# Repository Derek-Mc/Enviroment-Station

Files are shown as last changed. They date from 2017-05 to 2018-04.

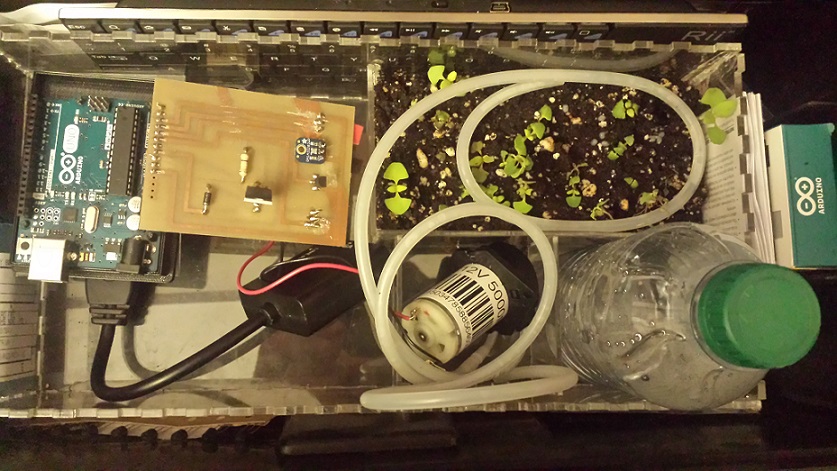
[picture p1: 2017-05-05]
Project Website/box2.jpg

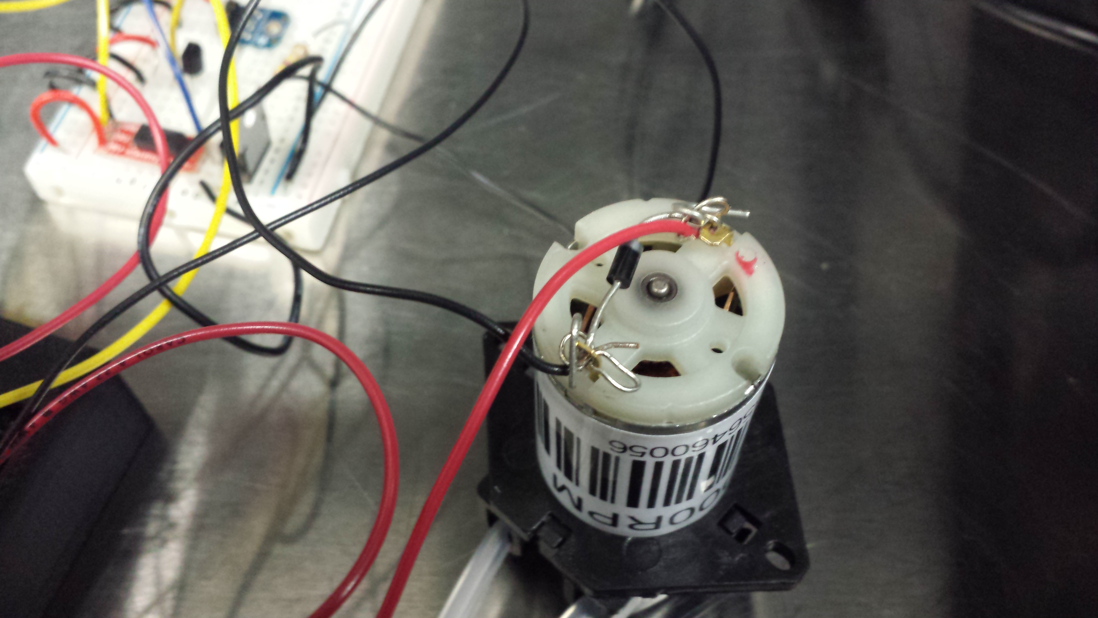
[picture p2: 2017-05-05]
Project Website/pump.jpg

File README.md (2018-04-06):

# Enviroment-Station
Keystone project from college (2017).

The objective of the project was to create an enviromantal monitoring station that would measure the humidity, light levels,
temperature, and soil moisture content of a plant.  This data is then sent to a server where the data is the pulled from and
displayed on an Android app and a website.

All files were made by myself with the exception of; Plant1.php, Plant_One_Hum.php, Plant_One_Light.php, Plant_One_Moist.php,
and Plant_One_Temp.php, which were created by my partner on the project.

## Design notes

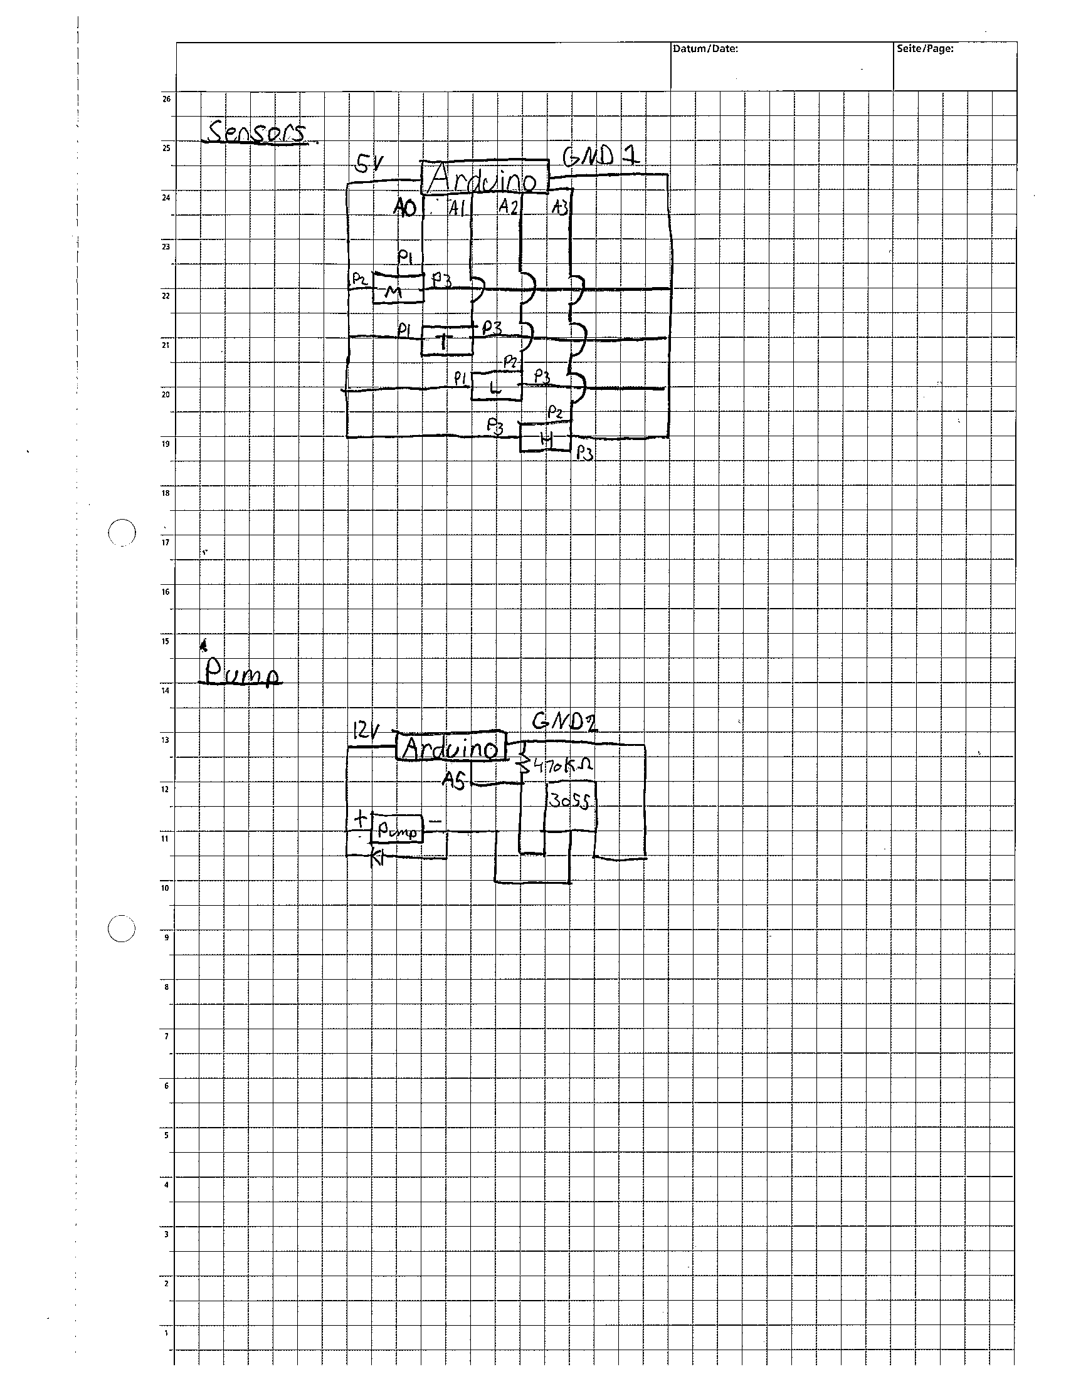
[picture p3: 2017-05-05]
Project Website/schematic.png

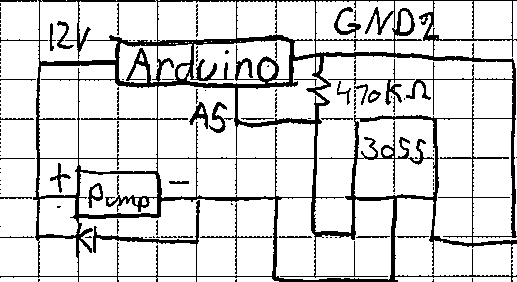
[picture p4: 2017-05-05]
Schematics/schematic2.png

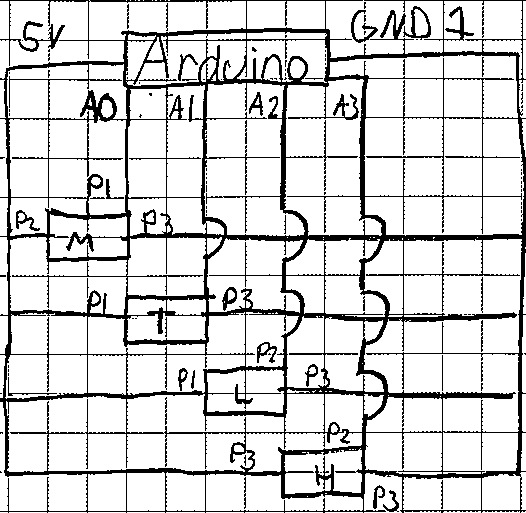
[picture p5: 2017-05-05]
Schematics/schematic1.png

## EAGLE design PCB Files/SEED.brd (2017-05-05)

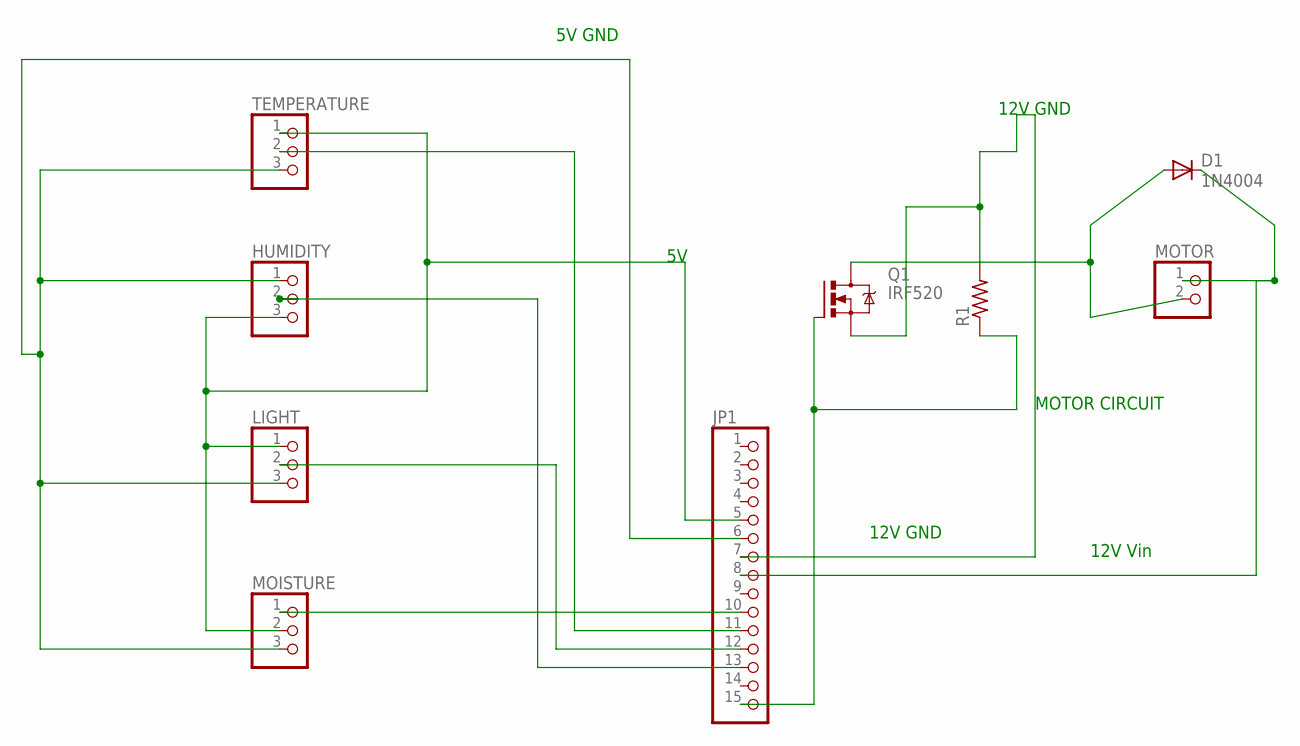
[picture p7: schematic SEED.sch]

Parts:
D1: 1N4004; DO41-10
HUMIDITY: PINHD-1X3; 1X03
JP1: PINHD-1X15; 1X15
LIGHT: PINHD-1X3; 1X03
MOISTURE: PINHD-1X3; 1X03
MOTOR: PINHD-1X2; 1X02
Q1: IRF520; TO220BV
R1: R-US_0207/12; 0207/12
TEMPERATURE: PINHD-1X3; 1X03

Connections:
unnamed: JP1.10, MOISTURE.1
unnamed: JP1.11, TEMPERATURE.2
unnamed: JP1.12, LIGHT.2
unnamed: HUMIDITY.2, JP1.13
unnamed: JP1.15, Q1.G, R1.1
unnamed: D1.A, MOTOR.2, Q1.D
unnamed: HUMIDITY.3, JP1.5, LIGHT.1, MOISTURE.2, TEMPERATURE.1
unnamed: D1.C, JP1.8, MOTOR.1
unnamed: JP1.7, Q1.S, R1.2
unnamed: HUMIDITY.1, JP1.6, LIGHT.3, MOISTURE.3, TEMPERATURE.3

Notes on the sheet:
MOTOR CIRCUIT
12V Vin
12V GND
5V GND

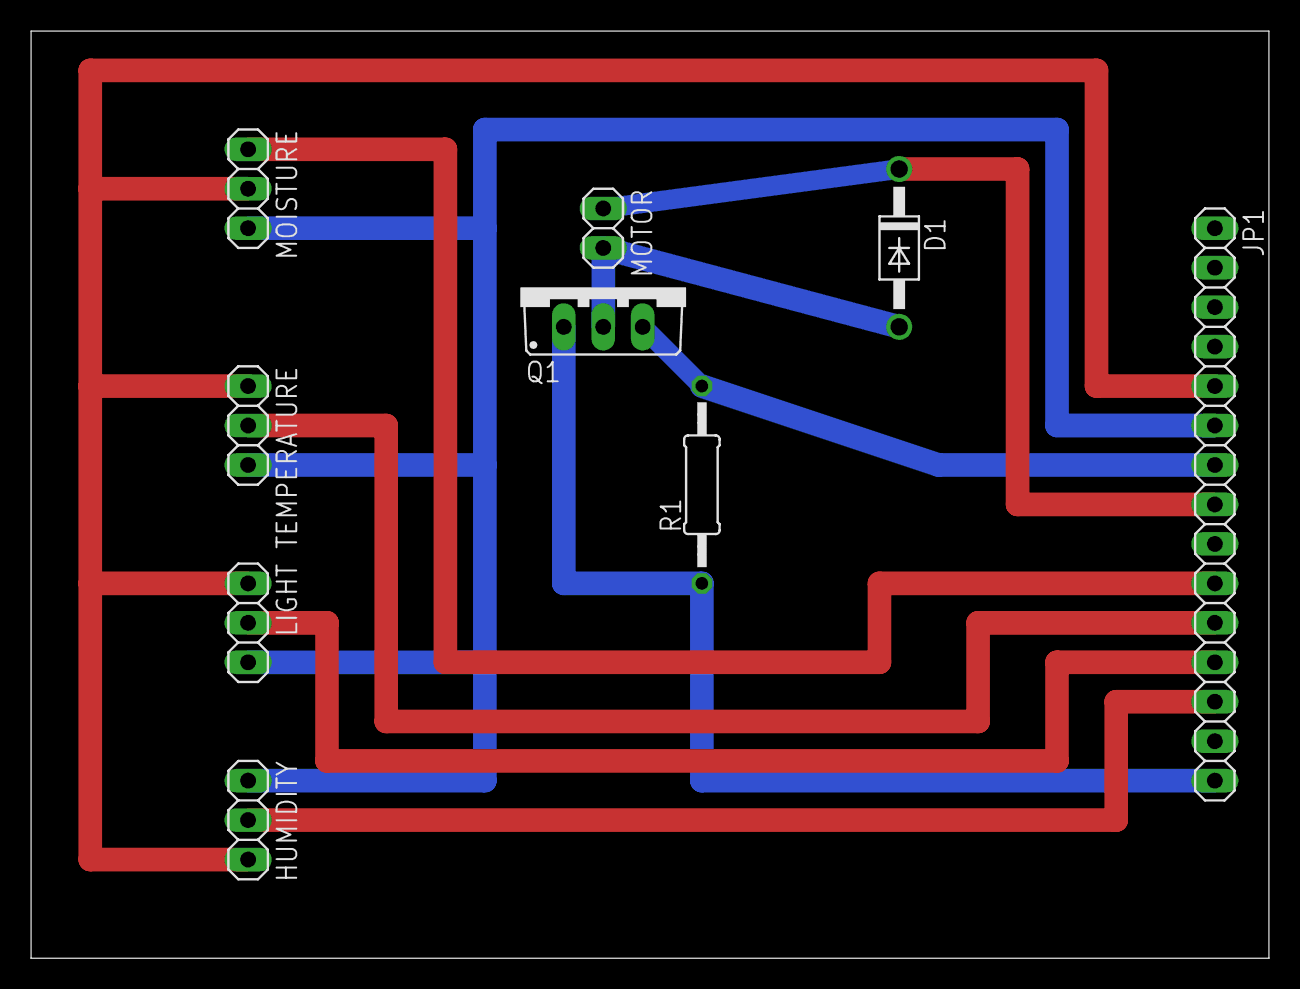
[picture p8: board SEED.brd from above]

Board: 2 copper layers, 79.7 x 59.7 mm, 9 parts (0 on the bottom side), 10 nets.

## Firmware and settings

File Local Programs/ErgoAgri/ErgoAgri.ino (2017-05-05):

int moistPin = A0;
int tempPin = A1;
int lightPin = A2;
int humidPin = A3;
int motorPin = A5;
float moist = 0.0;
float temp = 0.0;
float light = 0.0;
float humid = 0.0;
int waterFlag=0;
float dryAmount=72.0;
float hydrateAmount=45.0;
int boardID = 1;

void setup(){
  // put your setup code here, to run once:
  Serial.begin(9600);
  pinMode(moistPin, INPUT);//moisture
  pinMode(tempPin, INPUT);//temp
  pinMode(lightPin, INPUT);//light
  pinMode(humidPin, INPUT);//humid
  pinMode(motorPin, OUTPUT);//motor
}//end setup

void loop(){
  // put your main code here, to run repeatedly:
  //reset values to 0 to ensure that data being transmitted is new data (for testing purposes)
  moist = 0;
  temp = 0;
  light = 0;
  humid = 0;
  waterFlag = 0;

  //read data from pins and store into temp memory
  moist = analogRead(moistPin);
  moist = ((moist*0.9765625)/10);//convert value ranging from 0-1023 to a number between 0-99
  
  temp = analogRead(tempPin);
  temp=((((temp*5)/1024)-0.5)*100);//https://learn.adafruit.com/tmp36-temperature-sensor/using-a-temp-sensor
  
  humid = humidConv(temp);
  
  light = lightConv();
  
  Serial.println(moist);
  delay(1000);
  Serial.println(temp);
  delay(1000);
  Serial.println(light);
  delay(1000);
  Serial.println(humid);
  
  //watering if soil moisture is lower than allowed dry amount
  
	if(moist<=hydrateAmount)
	{
		digitalWrite(motorPin,HIGH);
    		delay(60000);
		//delay(1000);
    		digitalWrite(motorPin,LOW);
    		waterFlag=1;	
	}

	if((moist<=dryAmount)&&(waterFlag==0))
	{
    		digitalWrite(motorPin,HIGH);
    		delay(20000);
		//delay(500);
    		digitalWrite(motorPin,LOW);
                delay(40000);
    		waterFlag=2;
  	}
  
        if(waterFlag==0)
        {
          delay(60000);
        }

  //Ensures that the measuring data timing does float away over time.
  /*if(waterFlag==1){
    delay(57000);}
  else if(waterflag==2){
    delay(15000);
}
else{
    delay(57000);
}*/

  //1h between measurements
  for (int x = 0; x < 59; x++)
  {
    for (int y = 0; y < 60; y++)
    {
      delay(1000);
    }
  }//end of 1h wait
  
}

//https://learn.adafruit.com/adafruit-ga1a12s202-log-scale-analog-light-sensor/use-it
float lightConv()
{
  float rawRange = 1024;
  float logRange = 5.0;
  float data=0.0;
  float value=0.0;
  int raw=0;
  
  analogReference(EXTERNAL);
  for (int x=0;x<10;x++)
  {
    raw=analogRead(lightPin);
  }
   value = (raw*logRange/rawRange);
   data=pow(10,value);
    
  analogReference(DEFAULT);
  
  for(int x=0;x<10;x++)  
  {
    raw=analogRead(lightPin);
  }
  
  return data;
  
}
float humidConv(float temp)//http://bildr.org/2012/11/hih4030-arduino/
{
    int raw = analogRead(humidPin);
    float supplyVolt=5.0;
    float voltage = raw/1023.0*supplyVolt;
    float sensorRH = 161.0*voltage/supplyVolt - 25.8;
    float trueRH = sensorRH/(1.0546 - 0.0026*temp);
    
    return trueRH;
}

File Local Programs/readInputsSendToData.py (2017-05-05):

#!/usr/bin/python

import serial
import os

ser=serial.Serial('/dev/ttyACM0',9600)
while 1:
	print("Soil Moisture")
	moist=ser.readline()
	print(moist)
	
	print("Temperature")
	temp=ser.readline()
	print(temp)
	
	print("Light")
	light=ser.readline()
	print(light)
	
	print("Humidity")
	humid=ser.readline()
	print(humid)
	
	#write to file here
	text_file = open("data.txt","w")
	text_file.write(moist  + temp  + light  + humid )
	text_file.close()
		
	
	os.system("java writedata");
